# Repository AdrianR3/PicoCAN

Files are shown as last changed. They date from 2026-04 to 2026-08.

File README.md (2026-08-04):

# PicoCAN
PicoCAN is a custom devboard based on the RP2040 that features a built-in CAN controller and transceiver (the `MCP25625` to be exact).

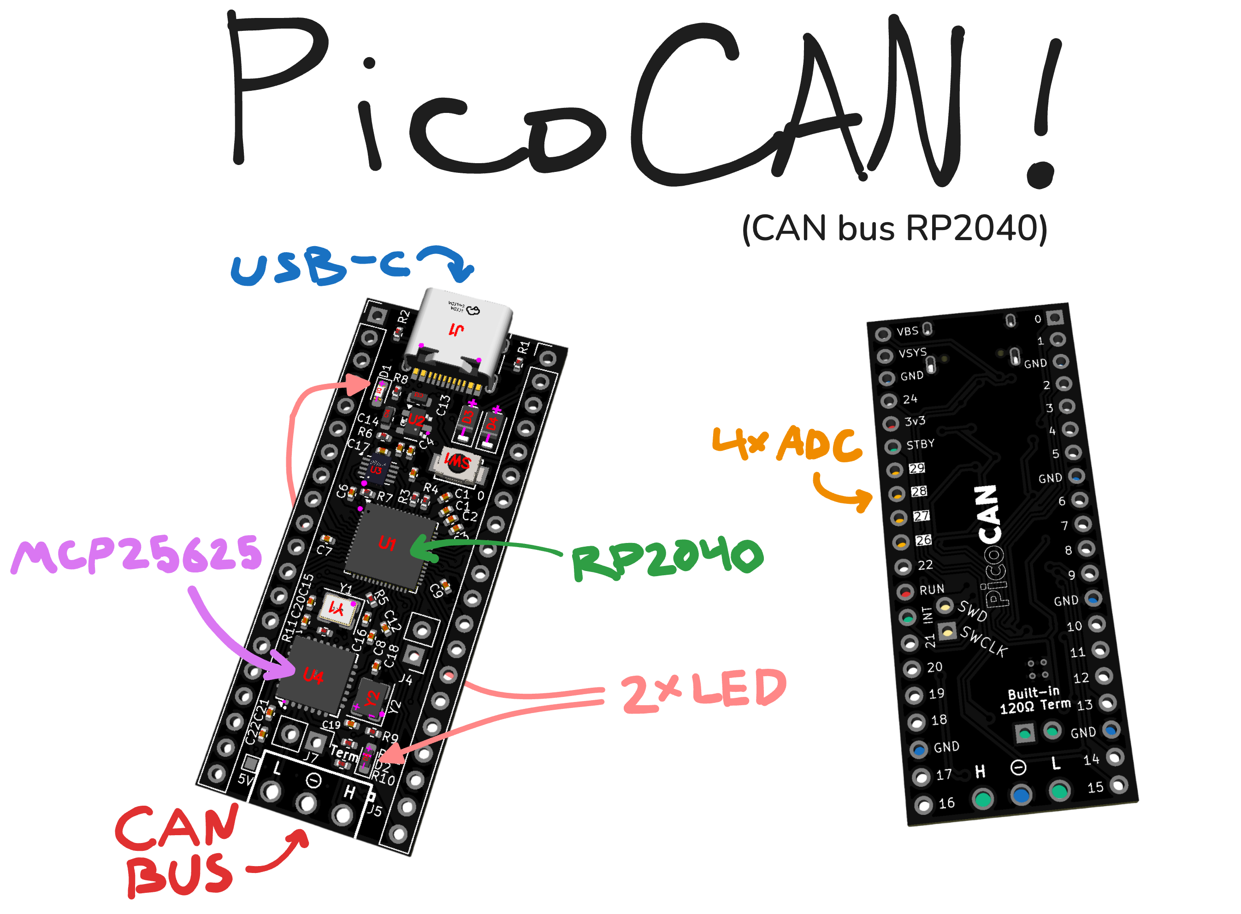
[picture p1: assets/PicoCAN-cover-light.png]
PicoCAN Cover Image


## Key Features
- USB-C connection for easy programming
- RP2040 based, with the same size as the Pi Pico
- CAN BUS using MCP25625
  - Built-in 120Ω termination resistor, which can be enabled by bridging the two pins near the `CANL` pin
- Support for powering with 5V through `VSYS` pin
- 28 usable GPIO pins, including 4 ADC pins
- Two on-board LEDs (Green and Red)
  - The red LED also shares pin `24` on the board
  - The green LED is not connected to any of the PicoCAN's pins

## Using the CAN bus

To interface with the CAN bus, you can use any library that supports the MCP25625. There are a few examples that use the [MCP_CAN](https://github.com/coryjfowler/MCP_CAN_lib) library in the `./firmware_examples` folder; they are adapted from https://github.com/coryjfowler/MCP_CAN_lib.

## Building the PicoCAN
The PicoCAN can be ordered from sites like JLCPCB (and optionally assembled too). The KiCAD source files are in `./KiCAD` and the production gerber files are in `./KiCAD/prod` along with the bom.

This is what JLC PCBA gets you! These don't have the headers soldered on yet.

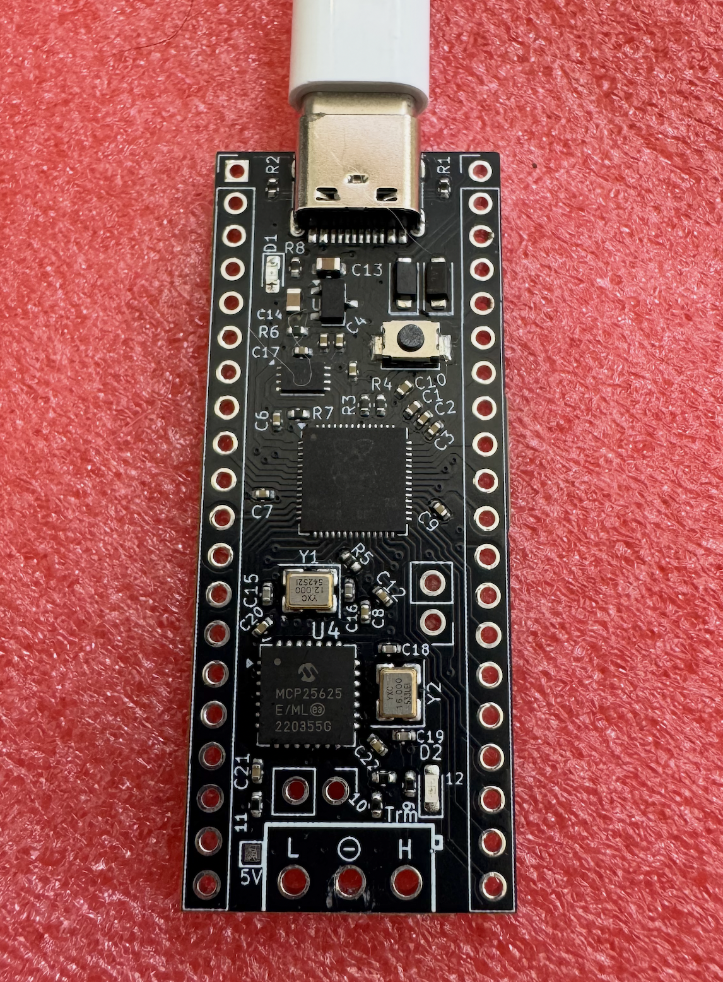
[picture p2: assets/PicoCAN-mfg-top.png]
Manufactured PicoCAN (Top Side)
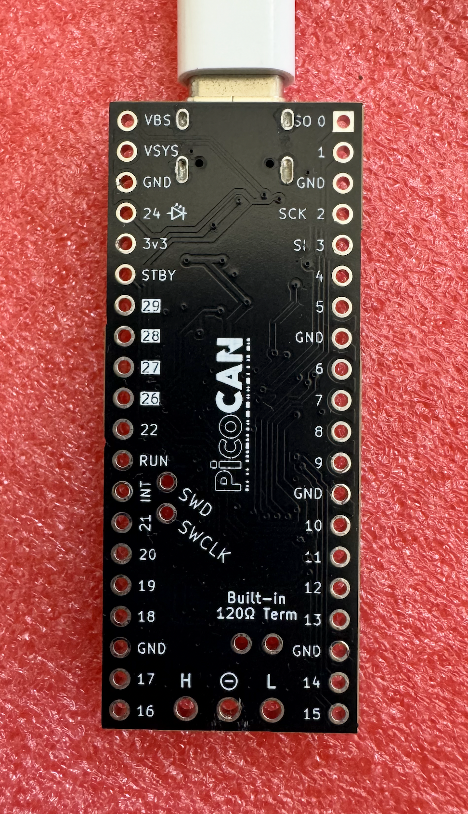
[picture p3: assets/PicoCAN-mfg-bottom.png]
Manufactured PicoCAN (Bottom Side)
 

## Images

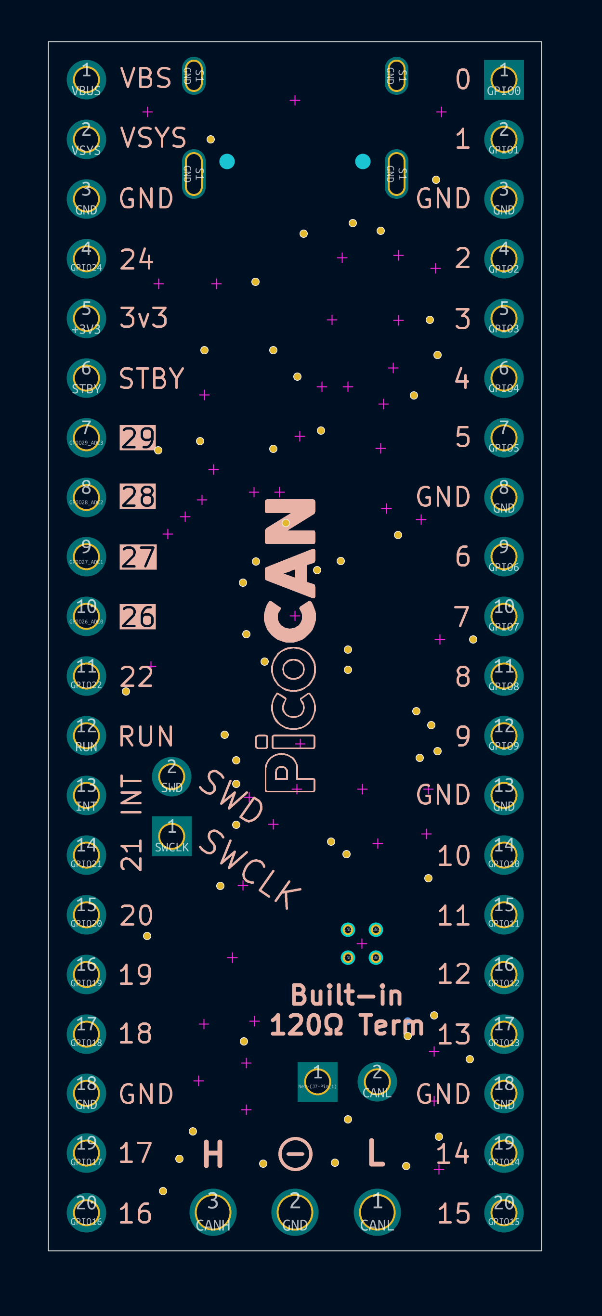
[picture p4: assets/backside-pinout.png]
Backside Pinout
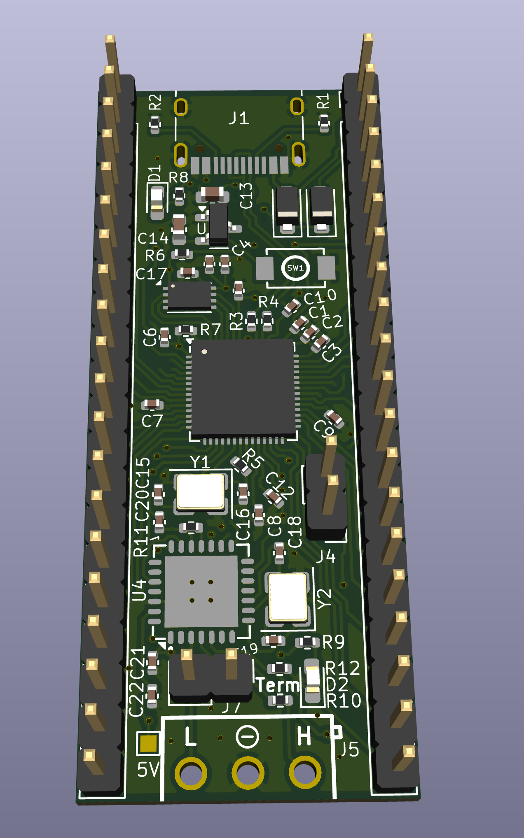
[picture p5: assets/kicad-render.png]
KiCad Render
 

## Schematic
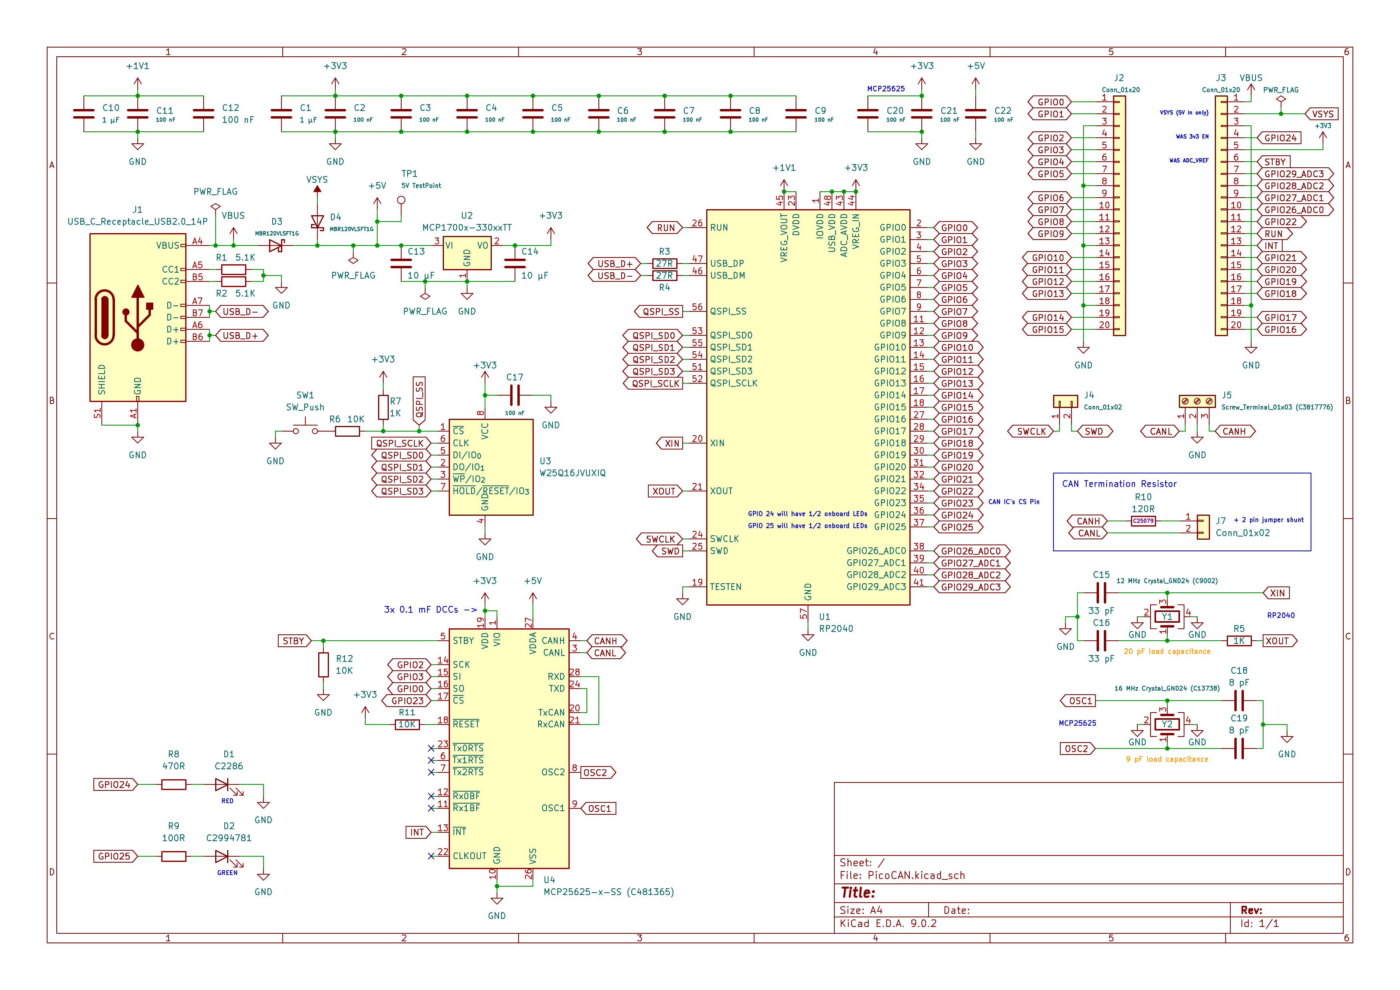
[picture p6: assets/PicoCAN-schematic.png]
PicoCAN Schematic


## BOM

| Name | Purpose | Quantity | Total Cost (USD) | Link | Distributor |
| --- | --- | --- | --- | --- | --- |
| 10kΩ Resistors | JLCPCB idle parts order to avoid ~8000 MOQ | 15 | 2.00 | https://jlcpcb.com/partdetail/26487-0402WGF1002TCE/C25744 | JLCPCB |
| JLCPCB PCB(A) | PCBA for the devboard | | 74.30 | | JLCPCB |
| Breakaway 2.54mm Headers | Soldering to PCB for GPIO, Termination Resistor Jumper, SWD + SWCLK pins | 220 | 5.73 | https://www.amazon.com/Jabinco-Breakable-Header-Connector-Arduino/dp/B0817JG3XN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 | Amazon |
| Socket Shorting Block Jumper Red Closed | Enabling Termination Resistor built into PCB (MOQ 10) | 5 | 1.40 | https://www.jameco.com/webapp/wcs/stores/servlet/ProductDisplay?productId=112432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 | Jameco |
| Terminal Block Header 3 Position Top Screw 3.5mm Solder Straight Thru-Hole 10A | Connecting to CAN BUS (CANL, CANH, GND) | 5 | 3.95 | https://www.jameco.com/webapp/wcs/stores/servlet/ProductDisplay?productId=2094514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 | Jameco |

Exhaustive PCB component BOM available at `./KiCAD/prod/PicoCAN.csv`.

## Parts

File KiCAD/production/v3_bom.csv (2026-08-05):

Designator | Footprint | Quantity | Value | LCSC Part #
C1, C10 | 0402 | 2 | 1 µF
C11, C12, C17, C2, C20, C21, C22, C3, C4, C5, C6, C7, C8, C9 | 0402 | 14 | 100 nF
C13, C14 | 0603 | 2 | 10 µF
C15, C16 | 0402 | 2 | 33 pF
C18, C19 | 0402 | 2 | 8 pF
D1 | 0603 | 1 | C2286
D2 | 0603 | 1 | C2994781
D3, D4 | D_SOD-123F | 2 | MBR120VLSFT1G
J1 | USB_C_Receptacle_HRO_TYPE-C-31-M-12 | 1 | USB_C_Receptacle_USB2.0_14P
J2, J3 | PinHeader_1x20_P2.54mm_Vertical | 2 | Conn_01x20
J4, J7 | PinHeader_1x02_P2.54mm_Vertical | 2 | Conn_01x02
J5 | CONN-TH_3P-P3.50_OSTTE030161 | 1 | Screw_Terminal_01x03 (C3817776)
R1, R2 | 0402 | 2 | 5.1K
R10 | 0402 | 1 | 120R
R11, R12, R6 | 0402 | 3 | 10K
R3, R4 | 0402 | 2 | 27R
R5, R7 | 0402 | 2 | 1K
R8 | 0402 | 1 | 470R
R9 | 0402 | 1 | 100R
SW1 | SW-SMD_L3.9-W3.0-P4.45 | 1 | SW_Push
TP1 | TestPoint_Pad_1.0x1.0mm | 1 | 5V TestPoint
U1 | QFN-56-1EP_7x7mm_P0.4mm_EP3.2x3.2mm | 1 | RP2040
U2 | SOT-23 | 1 | MCP1700x-330xxTT
U3 | Winbond_USON-8-1EP_3x2mm_P0.5mm_EP0.2x1.6mm | 1 | W25Q16JVUXIQ
U4 | QFN-28-1EP_6x6mm_P0.65mm_EP4.25x4.25mm | 1 | MCP25625x-x-ML
Y1 | Crystal_SMD_3225-4Pin_3.2x2.5mm | 1 | 12 MHz Crystal_GND24 (C9002)
Y2 | Crystal_SMD_3225-4Pin_3.2x2.5mm | 1 | 16 MHz Crystal_GND24 (C13738)

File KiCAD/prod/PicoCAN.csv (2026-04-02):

Designator | Quantity | Value | Comment | DNP | Exclude from BOM | Exclude from Board | Footprint | Datasheet | Notes
C1,C10 | 2 | 1 µF | C52923 |  |  |  | Capacitor_SMD:C_0402_1005Metric | ~
C2,C3,C4,C5,C6,C7,C8,C9,C11,C12,C17,C20,C21,C22 | 14 | 100 nF | C1525 |  |  |  | Capacitor_SMD:C_0402_1005Metric | ~
C13,C14 | 2 | 10 µF | C96446 |  |  |  | Capacitor_SMD:C_0603_1608Metric | ~
C15,C16 | 2 | 33 pF | C1562 |  |  |  | Capacitor_SMD:C_0402_1005Metric | ~
C18,C19 | 2 | 8 pF | C1578 |  |  |  | Capacitor_SMD:C_0402_1005Metric | ~ | 10 pF: C32949
D1 | 1 | C2286 | C2286 |  |  |  | LED_SMD:LED_0603_1608Metric_Pad1.05x0.95mm_HandSolder | ~
D2 | 1 | C2994781 | C2994781 |  |  |  | LED_SMD:LED_0603_1608Metric_Pad1.05x0.95mm_HandSolder | ~
D3,D4 | 2 | MBR120VLSFT1G | C223608 |  |  |  | Diode_SMD:D_SOD-123F | ~
J1 | 1 | USB_C_Receptacle_USB2.0_14P | C165948 |  |  |  | Connector_USB:USB_C_Receptacle_HRO_TYPE-C-31-M-12 | https://www.usb.org/sites/default/files/documents/usb_type-c.zip
J2,J3 | 2 | Conn_01x20 |  |  | Excluded from BOM |  | Connector_PinHeader_2.54mm:PinHeader_1x20_P2.54mm_Vertical | ~
J4,J7 | 2 | Conn_01x02 |  |  | Excluded from BOM |  | Connector_PinHeader_2.54mm:PinHeader_1x02_P2.54mm_Vertical | ~
J5 | 1 | Screw_Terminal_01x03 (C3817776) | C3817776 |  |  |  | easyeda2kicad:CONN-TH_3P-P3.50_OSTTE030161 | ~ | Look at C3818779
R1,R2 | 2 | 5.1K | C25905 |  |  |  | Resistor_SMD:R_0402_1005Metric | ~
R3,R4 | 2 | 27R | C25100 |  |  |  | Resistor_SMD:R_0402_1005Metric | ~
R5,R7 | 2 | 1K | C11702 |  |  |  | Resistor_SMD:R_0402_1005Metric | ~
R6,R11,R12 | 3 | 10K | C25744 |  |  |  | Resistor_SMD:R_0402_1005Metric | ~ | Basic: C25744, Extended: C176114
R8 | 1 | 470R | C25117 |  |  |  | Resistor_SMD:R_0402_1005Metric | ~
R9 | 1 | 100R | C25076 |  |  |  | Resistor_SMD:R_0402_1005Metric | ~
R10 | 1 | 120R | C25079 |  |  |  | Resistor_SMD:R_0402_1005Metric | ~
SW1 | 1 | SW_Push | C720477 |  |  |  | easyeda2kicad:SW-SMD_L3.9-W3.0-P4.45 | ~
TP1 | 1 | 5V TestPoint |  |  | Excluded from BOM |  | TestPoint:TestPoint_Pad_1.0x1.0mm | ~
U1 | 1 | RP2040 | C2040 |  |  |  | Package_DFN_QFN:QFN-56-1EP_7x7mm_P0.4mm_EP3.2x3.2mm | https://datasheets.raspberrypi.com/rp2040/rp2040-datasheet.pdf
U2 | 1 | MCP1700x-330xxTT | C39051 |  |  |  | Package_TO_SOT_SMD:SOT-23 | http://ww1.microchip.com/downloads/en/DeviceDoc/20001826D.pdf
U3 | 1 | W25Q16JVUXIQ | C2843335 |  |  |  | Package_SON:Winbond_USON-8-1EP_3x2mm_P0.5mm_EP0.2x1.6mm | https://www.winbond.com/resource-files/w25q128jv_dtr%20revc%2003272018%20plus.pdf | Look at P25Q32L-UXH-IR later
U4 | 1 | MCP25625-x-SS (C481365) | C481365 |  |  |  | easyeda2kicad:QFN-28_L6.0-W6.0-P0.65-BL-EP | http://ww1.microchip.com/downloads/en/DeviceDoc/20005282B.pdf
Y1 | 1 | 12 MHz Crystal_GND24 (C9002) | C9002 |  |  |  | Crystal:Crystal_SMD_3225-4Pin_3.2x2.5mm | ~
Y2 | 1 | 16 MHz Crystal_GND24 (C13738) | C13738 |  |  |  | Crystal:Crystal_SMD_3225-4Pin_3.2x2.5mm | ~

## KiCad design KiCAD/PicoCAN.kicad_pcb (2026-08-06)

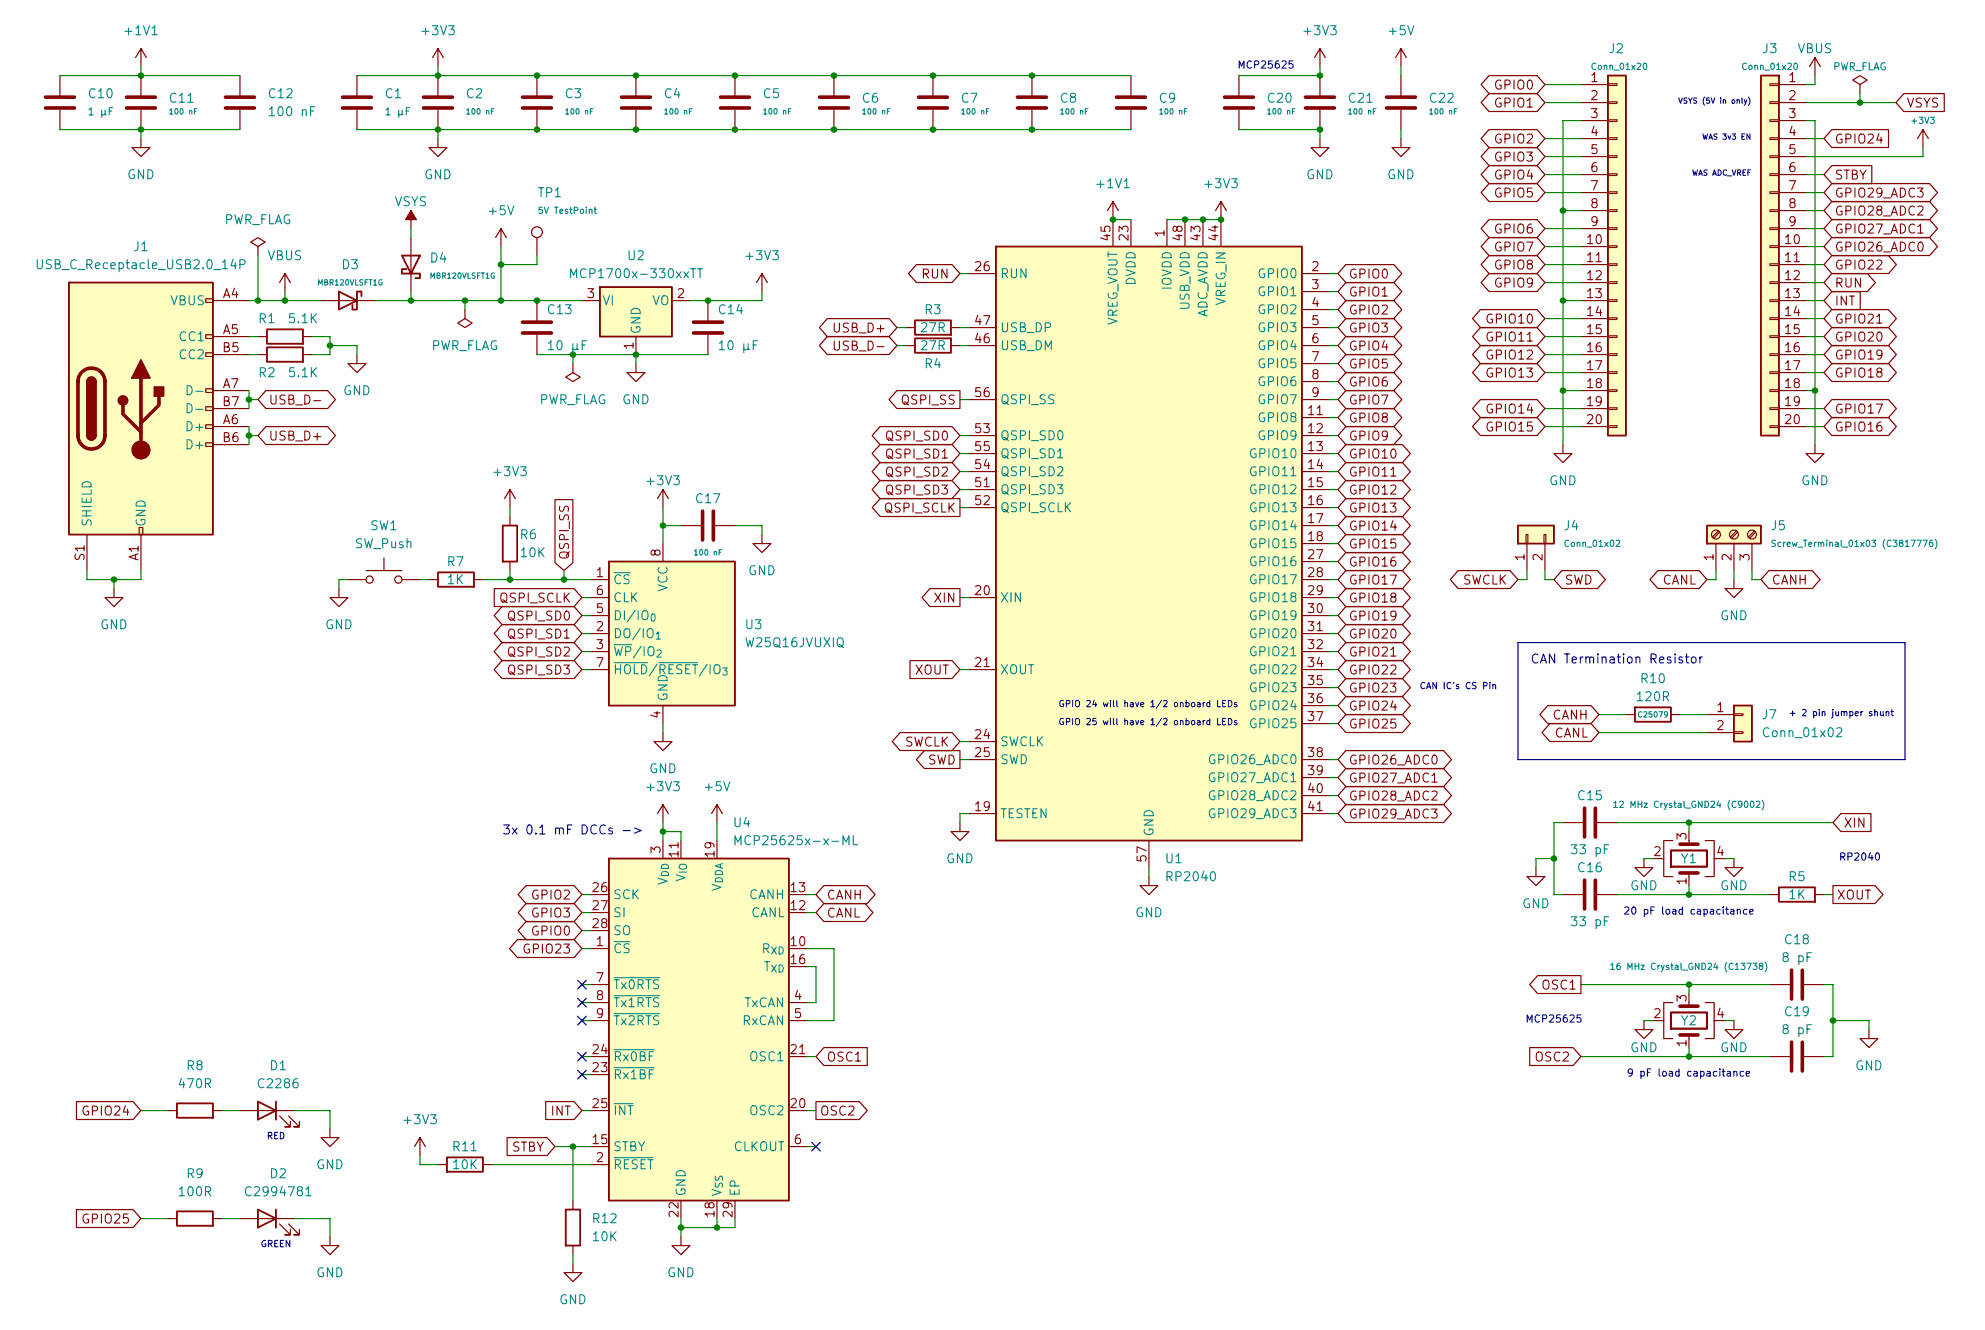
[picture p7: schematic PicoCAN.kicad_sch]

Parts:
C1, C10: 1 µF; C_0402_1005Metric; MPN C52923
C2, C3, C4, C5, C6, C7, C8, C9, C11, C12, C17, C20, C21, C22: 100 nF; C_0402_1005Metric; MPN C1525
C13, C14: 10 µF; C_0603_1608Metric; MPN C96446
C15, C16: 33 pF; C_0402_1005Metric; MPN C1562
C18, C19: 8 pF; C_0402_1005Metric; MPN C1578
D1: C2286; LED_0603_1608Metric_Pad1.05x0.95mm_HandSolder; MPN C2286
D2: C2994781; LED_0603_1608Metric_Pad1.05x0.95mm_HandSolder; MPN C2994781
D3, D4: MBR120VLSFT1G; D_SOD-123F; MPN C223608
J1: USB_C_Receptacle_USB2.0_14P; USB_C_Receptacle_HRO_TYPE-C-31-M-12; MPN C165948
J2, J3: Conn_01x20; PinHeader_1x20_P2.54mm_Vertical
J4, J7: Conn_01x02; PinHeader_1x02_P2.54mm_Vertical
J5: Screw_Terminal_01x03 (C3817776); CONN-TH_3P-P3.50_OSTTE030161; MPN C3817776
R1, R2: 5.1K; R_0402_1005Metric; MPN C25905
R3, R4: 27R; R_0402_1005Metric; MPN C25100
R5, R7: 1K; R_0402_1005Metric; MPN C11702
R6, R11, R12: 10K; R_0402_1005Metric; MPN C25744
R8: 470R; R_0402_1005Metric; MPN C25117
R9: 100R; R_0402_1005Metric; MPN C25076
R10: 120R; R_0402_1005Metric; MPN C25079
SW1: SW_Push; SW-SMD_L3.9-W3.0-P4.45; MPN C720477
TP1: 5V TestPoint; TestPoint_Pad_1.0x1.0mm
U1: RP2040; QFN-56-1EP_7x7mm_P0.4mm_EP3.2x3.2mm; MPN C2040
U2: MCP1700x-330xxTT; SOT-23; MPN C39051
U3: W25Q16JVUXIQ; Winbond_USON-8-1EP_3x2mm_P0.5mm_EP0.2x1.6mm; MPN C2843335
U4: MCP25625x-x-ML; QFN-28-1EP_6x6mm_P0.65mm_EP4.25x4.25mm
Y1: 12 MHz Crystal_GND24 (C9002); Crystal_SMD_3225-4Pin_3.2x2.5mm; MPN C9002
Y2: 16 MHz Crystal_GND24 (C13738); Crystal_SMD_3225-4Pin_3.2x2.5mm; MPN C13738

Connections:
+1V1: C10.1, C11.1, C12.1, U1.23 (DVDD), U1.45 (VREG_VOUT), U1.50 (DVDD)
+3V3: C1.1, C2.1, C3.1, C4.1, C5.1, C6.1, C7.1, C8.1, C9.1, C14.1, C17.2, C20.1, C21.1, J3.5, R6.1, R11.2, U1.1 (IOVDD), U1.10 (IOVDD), U1.22 (IOVDD), U1.33 (IOVDD), U1.42 (IOVDD), U1.43 (ADC_AVDD), U1.44 (VREG_IN), U1.48 (USB_VDD), U1.49 (IOVDD), U2.2 (VO), U3.8 (VCC), U4.3 (V_{DD}), U4.11 (V_{IO})
+5V: C13.1, C22.1, D3.1 (K), D4.1 (K), TP1.1 (1_1), U2.3 (VI), U4.19 (V_{DDA})
CANH: J5.3, R10.2, U4.13 (CANH)
CANL: J5.1, J7.2, U4.12 (CANL)
GND: C1.2, C2.2, C3.2, C4.2, C5.2, C6.2, C7.2, C8.2, C9.2, C10.2, C11.2, C12.2, C13.2, C14.2, C15.1, C16.1, C17.1, C18.2, C19.2, C20.2, C21.2, C22.2, D1.1 (K), D2.1 (K), J1.A1 (GND), J1.A12 (GND), J1.B1 (GND), J1.B12 (GND), J1.S1 (SHIELD), J2.3, J2.8, J2.13, J2.18, J3.3, J3.18, J5.2, R1.2, R2.2, R12.2, SW1.1, U1.19 (TESTEN), U1.57 (GND), U2.1 (GND), U3.4 (GND), U4.18 (V_{SS}), U4.22 (GND), U4.29 (EP), Y1.2, Y1.4, Y2.2, Y2.4
GPIO0: J2.1, U1.2 (GPIO0), U4.28 (SO)
GPIO1: J2.2, U1.3 (GPIO1)
GPIO2: J2.4, U1.4 (GPIO2), U4.26 (SCK)
GPIO3: J2.5, U1.5 (GPIO3), U4.27 (SI)
GPIO4: J2.6, U1.6 (GPIO4)
GPIO5: J2.7, U1.7 (GPIO5)
GPIO6: J2.9, U1.8 (GPIO6)
GPIO7: J2.10, U1.9 (GPIO7)
GPIO8: J2.11, U1.11 (GPIO8)
GPIO9: J2.12, U1.12 (GPIO9)
GPIO10: J2.14, U1.13 (GPIO10)
GPIO11: J2.15, U1.14 (GPIO11)
GPIO12: J2.16, U1.15 (GPIO12)
GPIO13: J2.17, U1.16 (GPIO13)
GPIO14: J2.19, U1.17 (GPIO14)
GPIO15: J2.20, U1.18 (GPIO15)
GPIO16: J3.20, U1.27 (GPIO16)
GPIO17: J3.19, U1.28 (GPIO17)
GPIO18: J3.17, U1.29 (GPIO18)
GPIO19: J3.16, U1.30 (GPIO19)
GPIO20: J3.15, U1.31 (GPIO20)
GPIO21: J3.14, U1.32 (GPIO21)
GPIO22: J3.11, U1.34 (GPIO22)
GPIO23: U1.35 (GPIO23), U4.1 (~CS)
GPIO24: J3.4, R8.1, U1.36 (GPIO24)
GPIO25: R9.1, U1.37 (GPIO25)
GPIO26_ADC0: J3.10, U1.38 (GPIO26_ADC0)
GPIO27_ADC1: J3.9, U1.39 (GPIO27_ADC1)
GPIO28_ADC2: J3.8, U1.40 (GPIO28_ADC2)
GPIO29_ADC3: J3.7, U1.41 (GPIO29_ADC3)
INT: J3.13, U4.25 (~INT)
unnamed: C16.2, R5.1, Y1.1
unnamed: D1.2 (A), R8.2
unnamed: D2.2 (A), R9.2
unnamed: J1.A5 (CC1), R1.1
unnamed: J1.B5 (CC2), R2.1
unnamed: J7.1, R10.1
unnamed: R7.1, SW1.2
unnamed: R4.2, U1.46 (USB_DM)
unnamed: R3.2, U1.47 (USB_DP)
unnamed: U4.5 (RxCAN), U4.10 (R_{XD})
unnamed: U4.4 (TxCAN), U4.16 (T_{XD})
unnamed: R11.1, U4.2 (~RESET)
OSC1: C18.1, U4.21 (OSC1), Y2.3
OSC2: C19.1, U4.20 (OSC2), Y2.1
QSPI_SCLK: U1.52 (QSPI_SCLK), U3.6 (CLK)
QSPI_SD0: U1.53 (QSPI_SD0), U3.5 (DI/IO_{0})
QSPI_SD1: U1.55 (QSPI_SD1), U3.2 (DO/IO_{1})
QSPI_SD2: U1.54 (QSPI_SD2), U3.3 (~WP/IO_{2})
QSPI_SD3: U1.51 (QSPI_SD3), U3.7 (~HOLD/~RESET/IO_{3})
QSPI_SS: R6.2, R7.2, U1.56 (QSPI_SS), U3.1 (~CS)
RUN: J3.12, U1.26 (RUN)
STBY: J3.6, R12.1, U4.15 (STBY)
SWCLK: J4.1, U1.24 (SWCLK)
SWD: J4.2, U1.25 (SWD)
USB_D+: J1.A6 (D+), J1.B6 (D+), R3.1
USB_D-: J1.A7 (D-), J1.B7 (D-), R4.1
VBUS: D3.2 (A), J1.A4 (VBUS), J1.A9 (VBUS), J1.B4 (VBUS), J1.B9 (VBUS), J3.1
VSYS: D4.2 (A), J3.2
XIN: C15.2, U1.20 (XIN), Y1.3
XOUT: R5.2, U1.21 (XOUT)

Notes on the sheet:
WAS 3v3 EN
CAN IC's CS Pin
GPIO 24 will have 1/2 onboard LEDs
3x 0.1 mF DCCs ->
CAN Termination Resistor
9 pF load capacitance
VSYS (5V in only)
GREEN
+ 2 pin jumper shunt
MCP25625
20 pF load capacitance
GPIO 25 will have 1/2 onboard LEDs
RED
WAS ADC_VREF
RP2040

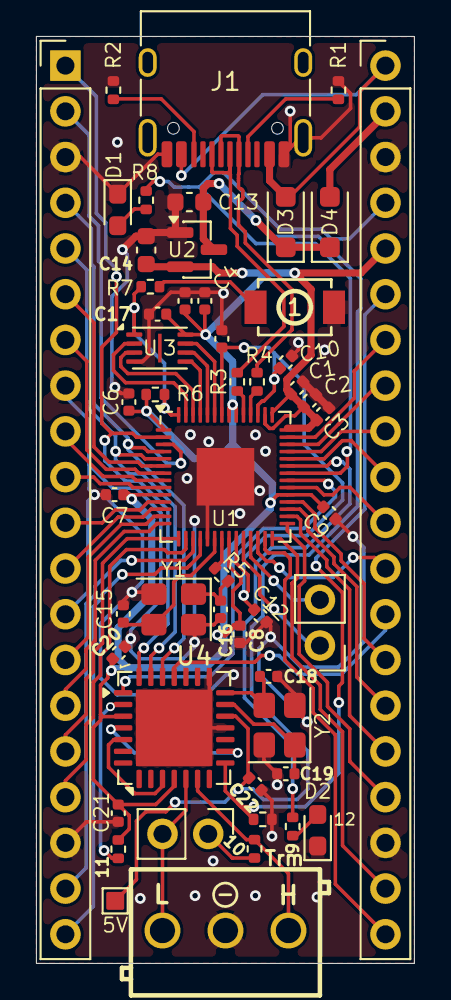
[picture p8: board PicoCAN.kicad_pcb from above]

Board: 2 copper layers, 21.0 x 51.5 mm, 52 parts (0 on the bottom side), 67 nets.

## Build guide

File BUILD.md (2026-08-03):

# PicoCAN Build

Build and implementation for the PicoCAN here. ETA: 2 days

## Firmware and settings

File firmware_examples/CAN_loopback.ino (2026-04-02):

// Example adapted from https://github.com/coryjfowler/MCP_CAN_lib/

/* CAN Loopback Example
 * This example sends a message once a second and receives that message
 *   no CAN bus is required.  This example will test the functionality 
 *   of the protocol controller, and connections to it.
 *   
 *   Written By: Cory J. Fowler - October 5th 2016
 */

#include <mcp_can.h>
#include <SPI.h>

// CAN TX Variables
unsigned long prevTX = 0;                                        // Variable to store last execution time
const unsigned int invlTX = 1000;                                // One second interval constant
byte data[] = {0xAA, 0x55, 0x01, 0x10, 0xFF, 0x12, 0x34, 0x56};  // Generic CAN data to send

// CAN RX Variables
long unsigned int rxId;
unsigned char len;
unsigned char rxBuf[8];

// Serial Output String Buffer
char msgString[128];

// CAN0 INT and CS
#define CAN0_INT 2 // Whatever this pin is must be physically connected the the PicoCAN's external INT pin
MCP_CAN CAN0(23);  // PicoCAN has the RP2040's GPIO23 internally connected to the MCP25625's CS pin


void setup()
{
  Serial.begin(115200);  // CAN is running at 500,000BPS; 115,200BPS is SLOW, not FAST, thus 9600 is crippling.
  
  // Initialize MCP2515 running at 16MHz with a baudrate of 500kb/s and the masks and filters disabled.
  if(CAN0.begin(MCP_ANY, CAN_500KBPS, MCP_16MHZ) == CAN_OK)
    Serial.println("MCP2515 Initialized Successfully!");
  else
    Serial.println("Error Initializing MCP2515...");
  
  // Since we do not set NORMAL mode, we are in loopback mode by default.
  //CAN0.setMode(MCP_NORMAL);

  pinMode(CAN0_INT, INPUT);                           // Configuring pin for /INT input
  
  Serial.println("MCP2515 Library Loopback Example...");
}

void loop()
{
  if(!digitalRead(CAN0_INT))                          // If CAN0_INT pin is low, read receive buffer
  {
    CAN0.readMsgBuf(&rxId, &len, rxBuf);              // Read data: len = data length, buf = data byte(s)
    
    if((rxId & 0x80000000) == 0x80000000)             // Determine if ID is standard (11 bits) or extended (29 bits)
      sprintf(msgString, "Extended ID: 0x%.8lX  DLC: %1d  Data:", (rxId & 0x1FFFFFFF), len);
    else
      sprintf(msgString, "Standard ID: 0x%.3lX       DLC: %1d  Data:", rxId, len);
  
    Serial.print(msgString);
  
    if((rxId & 0x40000000) == 0x40000000){            // Determine if message is a remote request frame.
      sprintf(msgString, " REMOTE REQUEST FRAME");
      Serial.print(msgString);
    } else {
      for(byte i = 0; i<len; i++){
        sprintf(msgString, " 0x%.2X", rxBuf[i]);
        Serial.print(msgString);
      }
    }
        
    Serial.println();
  }
  
  if(millis() - prevTX >= invlTX){                    // Send this at a one second interval. 
    prevTX = millis();
    byte sndStat = CAN0.sendMsgBuf(0x100, 8, data);
    
    if(sndStat == CAN_OK)
      Serial.println("Message Sent Successfully!");
    else
      Serial.println("Error Sending Message...");

  }
}

/*********************************************************************************************************
  END FILE
*********************************************************************************************************/

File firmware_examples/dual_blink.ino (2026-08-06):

#define RED_LED_PIN 24
#define GREEN_LED_PIN 25

// Sets up an interrupt to enter BOOTSEL mode when a pin is pulled low
void setupEmergencyBoot(uint8_t pin) {
  pinMode(pin, INPUT_PULLUP);
  
  attachInterrupt(digitalPinToInterrupt(pin), []() {
    reset_usb_boot(0, 0); 
  }, FALLING);
}

void setup() {
  pinMode(RED_LED_PIN, OUTPUT);
  pinMode(GREEN_LED_PIN, OUTPUT);

  setupEmergencyBoot(15);
}

void loop() { // Alternates between red and green onboard LEDs
  digitalWrite(RED_LED_PIN, HIGH);
  digitalWrite(GREEN_LED_PIN, LOW);

  delay(500);

  digitalWrite(RED_LED_PIN, LOW);
  digitalWrite(GREEN_LED_PIN, HIGH);

  delay(500);
}

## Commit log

2026-03-17 Initial schematic
    Everything before breaking out the GPIO pins
    [PicoCAN.kicad_pcb, PicoCAN.kicad_sch]
2026-03-19 Add MCP25625 and more progress
    [PicoCAN.kicad_sch]
2026-03-29 Finished MCP25625
    [PicoCAN.kicad_sch]
2026-03-30 Footprints and schematic (w/load caps) finished
    [PicoCAN.kicad_sch]
2026-03-30 PCB Layout
    [PicoCAN.kicad_pcb, PicoCAN.kicad_sch]
2026-03-31 Finished Traces
    [PicoCAN.kicad_pcb, PicoCAN.kicad_sch]
2026-04-01 Finished PCB
    [PicoCAN.kicad_pcb]
2026-04-02 Add kicad-render.png
2026-04-02 Finished PCB from earlier
    [PicoCAN.kicad_pcb, PicoCAN.kicad_sch]
2026-04-02 Add PROD files
    [PicoCAN-B_Cu.gbr, PicoCAN-B_Mask.gbr, PicoCAN-B_Paste.gbr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]
2026-04-03 Enhance BOM
2026-04-03 Upload schematic image to assets
2026-04-03 Add schematic image
2026-08-05 MCP25625 issue fixed by rewire
    [PicoCAN.kicad_pcb, PicoCAN.kicad_sch]
2026-08-05 v2 and v3 production files
    [v2_bom.csv, v2_designators.csv, v2_positions.csv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]
2026-08-06 Swap R6 and R7
    Fixes issue of button not activating BOOTSEL mode
    [PicoCAN.kicad_pcb, PicoCAN.kicad_sch]
